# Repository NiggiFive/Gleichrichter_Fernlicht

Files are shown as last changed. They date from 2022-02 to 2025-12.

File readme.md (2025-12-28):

# Gleichrichter Fernlicht PCB#
Schaltung stammt von hier: https://fahrradzukunft.de/14/mosfet-gleichrichter
Serienkondensator von 390uF antiparallel hat sich als optimum herausgestellt (im Vgl. zu 330uF und 560uF)
Spannungsfestigkeit Kondensator: 35V (Großzügig)

Verwendete Mosfets:
N-Kanal: IRLML 0030
P-Kanal: TSM 3401 -> Kann aber nur max. 12V VGS

Anforderungen Mosfets:
möglichst niedriges RDS_on
30V VDSmax (großzügig)
Am besten möglichst hohes VGS_max -> 20V
Gate-Source sieht immer ca. die Ausgangsspannung -> 12V Reichen locker für 2 LEDs in Reihe mit jew. 6V am Ausgang. Je höhere Ausgangsspannungen auftreten können desto höher muss VGS_max sein.

Zenerdioden Schützen Gate vor zu hohen Spannungen. Aber auch nur kurzfristig, denn die können den Strom nicht ab. Zenerspannungen sollten also unter dem VGS_max sein!

Bei erster Version war Fehler im Layout: Die Pin-Reihenfolge der Standard-Mosfet-Symbole passt nicht zum SOT-23 Gehäuse.
Mosfets mussten daher auf dem Kopf gelötet werden.
Funktioniert so aber gut.

Ist jetzt im Schaltplan korrigiert aber das Layout  noch nicht fertig. (Falls nochmal aufgebaut wird)

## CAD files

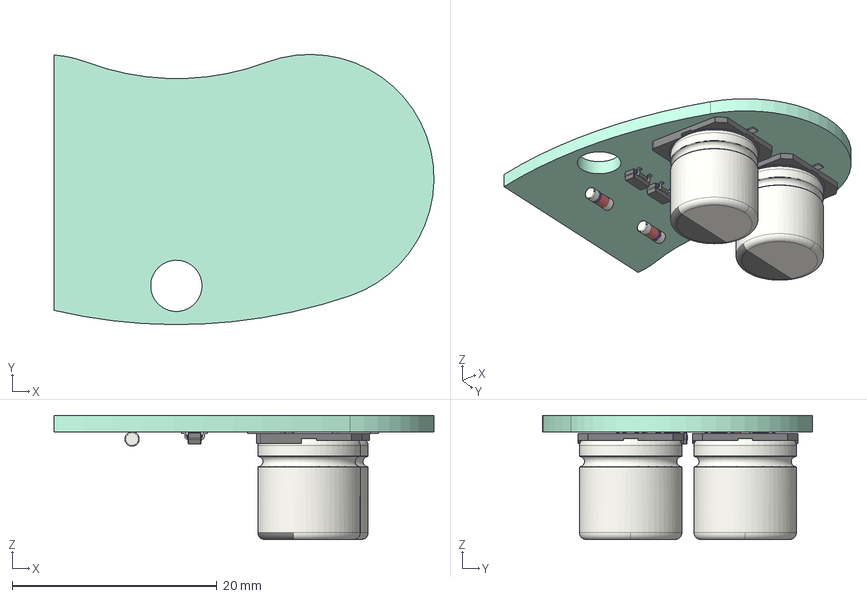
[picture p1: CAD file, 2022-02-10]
Gleichrichter_Fernlicht.step
37.1 x 26.4 x 12.1 mm
Pcb_96b
C1_CP_Elec_10x105_509557f2df9b x 2
Q4_SOT_23_db67c2e524e7 x 4
D2_D_MiniMELF_Standard_877587056aee x 2

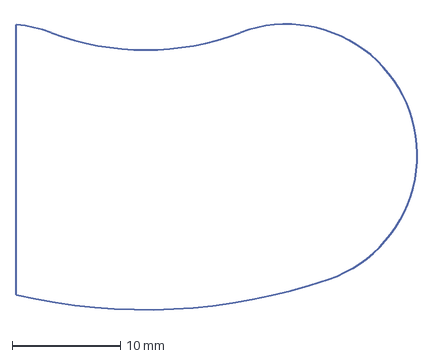
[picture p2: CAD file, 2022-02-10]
Jan/Leiterplatte.dxf
37.7 x 28.0 mm

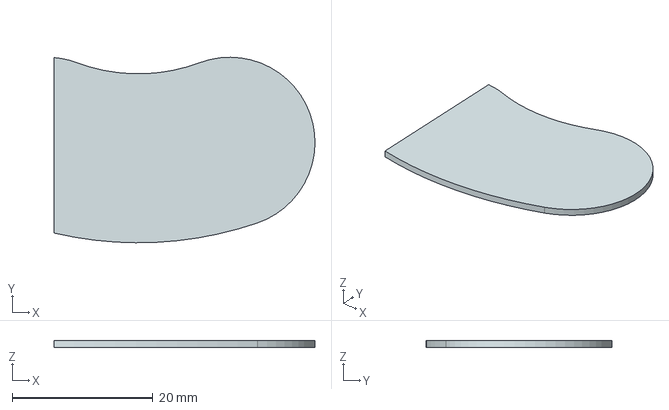
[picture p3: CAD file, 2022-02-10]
Jan/Leiterplatte_stp.stp
37.1 x 26.4 x 1.00 mm

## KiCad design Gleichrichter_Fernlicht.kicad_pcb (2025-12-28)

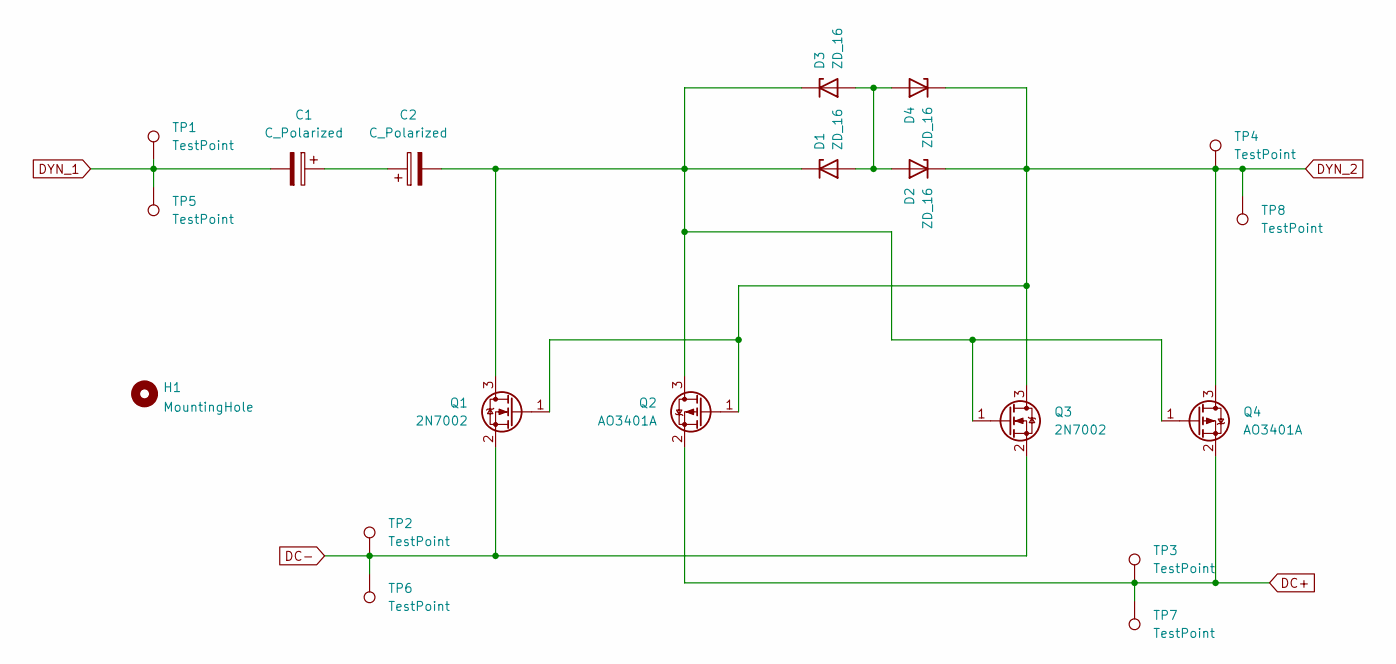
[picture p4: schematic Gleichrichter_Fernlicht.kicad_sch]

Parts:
C1, C2: C_Polarized; CP_Elec_10x10.5
D1, D2: ZD_16; D_SOD-123
D3, D4: ZD_16; D_MiniMELF_Handsoldering
H1: MountingHole; MountingHole_5mm
Q1, Q3: 2N7002; SOT-23_Handsoldering
Q2, Q4: AO3401A; SOT-23_Handsoldering
TP1, TP2, TP3, TP4, TP5, TP6, TP7, TP8: TestPoint; TestPoint_Pad_2.5x2.5mm

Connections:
DC+: Q2.2 (S), Q4.2 (S), TP3.1, TP7.1
DC-: Q1.2 (S), Q3.2 (S), TP2.1, TP6.1
DYN_1: C1.2, TP1.1, TP5.1
DYN_2: D2.1 (K), D4.1 (K), Q1.1 (G), Q2.1 (G), Q3.3 (D), Q4.3 (D), TP4.1, TP8.1
unnamed: C1.1, C2.1
unnamed: D1.2 (A), D2.2 (A), D3.2 (A), D4.2 (A)
unnamed: C2.2, D1.1 (K), D3.1 (K), Q1.3 (D), Q2.3 (D), Q3.1 (G), Q4.1 (G)

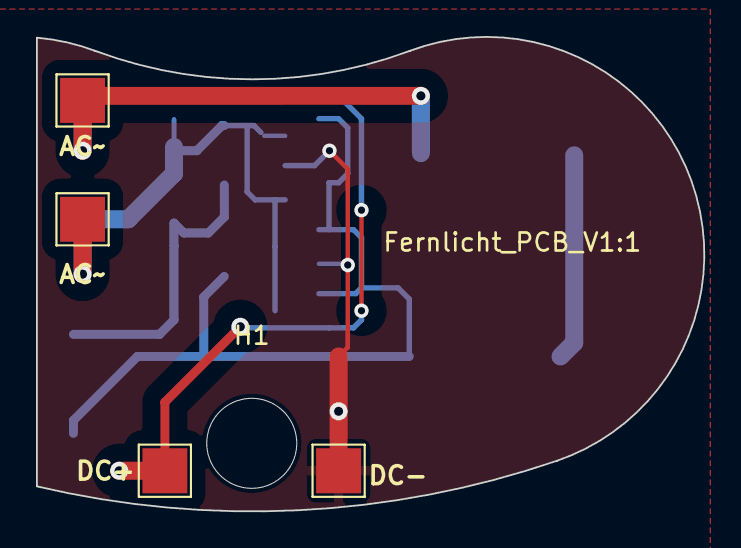
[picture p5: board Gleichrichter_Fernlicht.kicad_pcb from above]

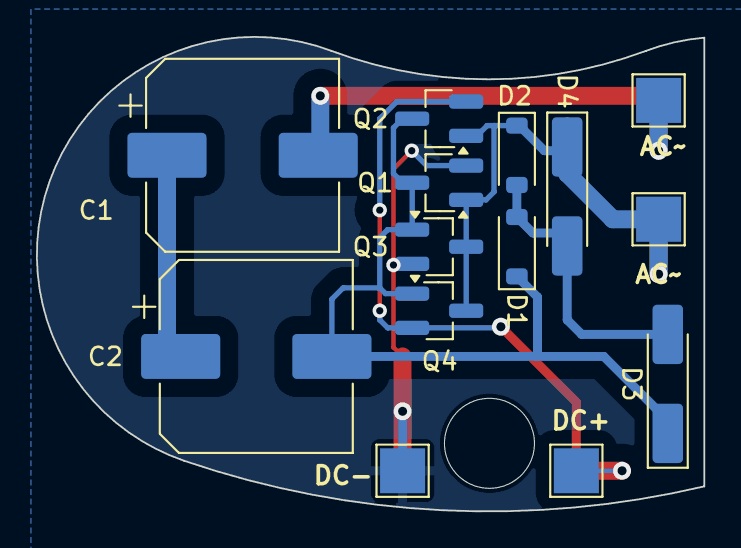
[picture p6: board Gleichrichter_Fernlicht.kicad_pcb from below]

Board: 2 copper layers, 37.1 x 26.4 mm, 19 parts (14 on the bottom side), 7 nets.

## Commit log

2022-02-08 Schaltplan gezeichnet und Bauteile platziert
    [Gleichrichter_Fernlicht.kicad_pcb, Gleichrichter_Fernlicht.kicad_sch]
2022-02-10 Dateien fuer Leiterplattenumriss von Jan hinzugefuegt
    [Leiterplatte.dxf, Leiterplatte_stp.stp]
2022-02-10 Kontur von Jan importiert und gelayoutet. Evtl. noch Kupferflaechen machen?
    [Gleichrichter_Fernlicht.kicad_pcb, Gleichrichter_Fernlicht.kicad_sch, Gleichrichter_Fernlicht.step]
2022-02-17 Stand der zu jlcpcb geschickt wurde
    [Gleichrichter_Fernlicht-CuBottom.gbr, Gleichrichter_Fernlicht-CuTop.gbr, Gleichrichter_Fernlicht-EdgeCuts.gbr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]
2022-04-24 Standard Mosfet-Symbol hat nicht zu SOT-23 Footprint gepasst. (Drain und Source vertauscht). Jetzt korrigiert. Layout noch nicht fertig. Hotfix: Transistoren auf erster Platine verkehrt herum drauflö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
    [Gleichrichter_Fernlicht.kicad_pcb, Gleichrichter_Fernlicht.kicad_sch]
2025-12-28 update: Layout korrigiert und an jlc geschickt
    [Gleichrichter_Fernlicht-CuBottom.gbr, Gleichrichter_Fernlicht-CuTop.gbr, Gleichrichter_Fernlicht-EdgeCuts.gbr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]
